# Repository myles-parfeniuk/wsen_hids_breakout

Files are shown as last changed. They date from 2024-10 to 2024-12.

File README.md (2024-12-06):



<summary>Table of Contents</summary>
<ol>
<li><a href="#about">About</a></li>
<li><a href="#pcbway-sponsorship">PCBWay Sponsorship</a></li>
<li><a href="#gerber-files">Gerber Files</a></li>
<li><a href="#pcb-renders">PCB Renders</a></li>
<li><a href="#schematic-and-layout">Schematic and Layout</a></li>
<li><a href="#operating-voltages">Operating Voltages</a></li>
<li><a href="#contact">Contact</a></li>
</ol>

# About
Breakout board for [Würth Elektronik 2525020210002](https://www.we-online.com/en/components/products/WSEN-HIDS) I2C humidity w/ integrated temperature sensor IC.   
This repo contains all the schematic and layout files in the form of a KiCad project, they can be found within the `kicad` directory.
<p align="right">(<a href="#readme-top">back to top</a>)</p>

# PCBWay Sponsorship
Special thanks to PCBWay for reaching out to sponsor this project and provide access to their excellent service.  
PCBWay supports the DIY and open source community as well as students with sponsorships and contests frequently.   
Show them some love and consider having your next project fabricated by them: 

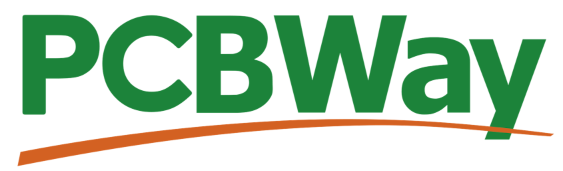
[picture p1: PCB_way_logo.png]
 

Order [here](https://www.pcbway.com/) today.

The boards manufactured by PCBWay had quality that exceeded my expectations.  
The silk screen was less smudged and noticeably more detailed than other fab houses I've used before. All 5 of the boards in my order had no defects, both cosmetic, and functionally.   

The shipping was also insanely quick; I live overseas from China, despite that, with standard shipping the boards were at my place within 2 weeks of uploading the gerbers.    
Their website also had an easy to follow [guide](https://www.pcbway.com/blog/help_center/Generate_Gerber_file_from_Kicad.html) on the settings they require for generated gerbers, this made ordering a breeze. Their [capabilities page](https://www.pcbway.com/capabilities.html) was also easy to follow for setting the constraints within KiCad.  

Overall, I was very satisfied with the result, I'll definitely be using them for any future projects.  

**NOTE:**  

The renders look different from the photos below, as these were for revision 1.0. The renders and KiCad files are for the newest revision, 1.1.

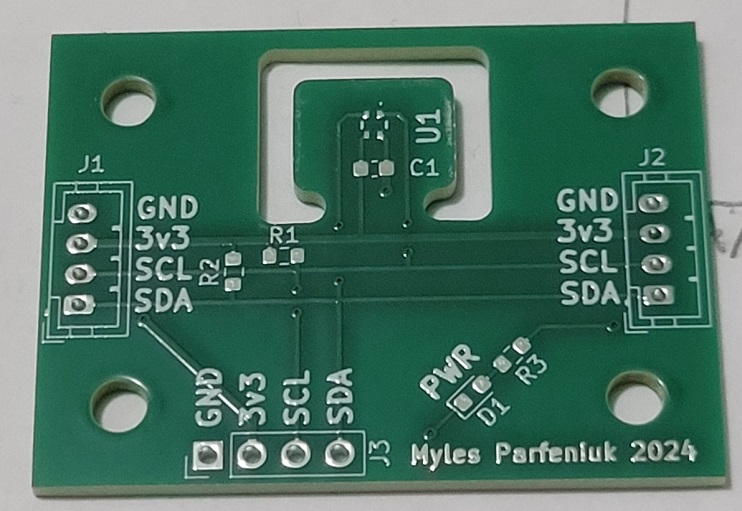
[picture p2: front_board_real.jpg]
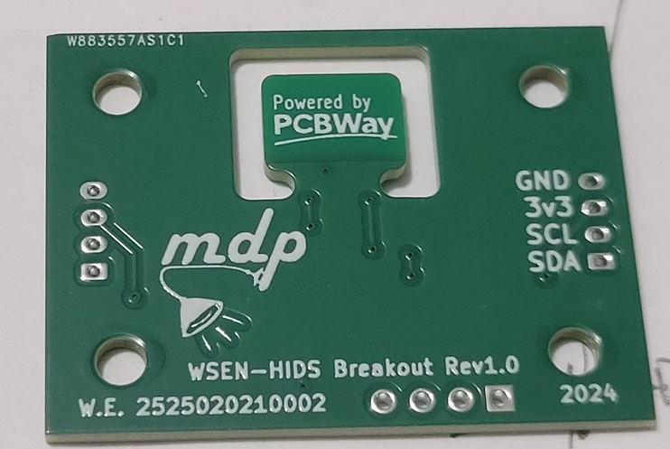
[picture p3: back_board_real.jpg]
  

<p align="right">(<a href="#readme-top">back to top</a>)</p>

# Gerber Files
Generated gerber and drill files can be found within the gerbers.7z archive.   
These files were generated according to PCBWay's desired settings, thus, they can be used to order the boards from them without re-plotting.
<p align="right">(<a href="#readme-top">back to top</a>)</p>

# PCB Renders
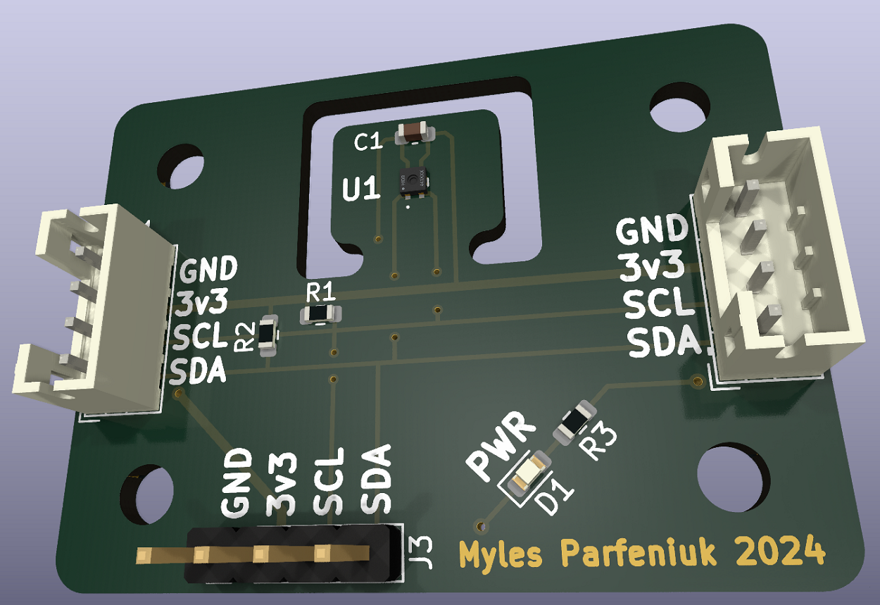
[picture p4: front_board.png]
  

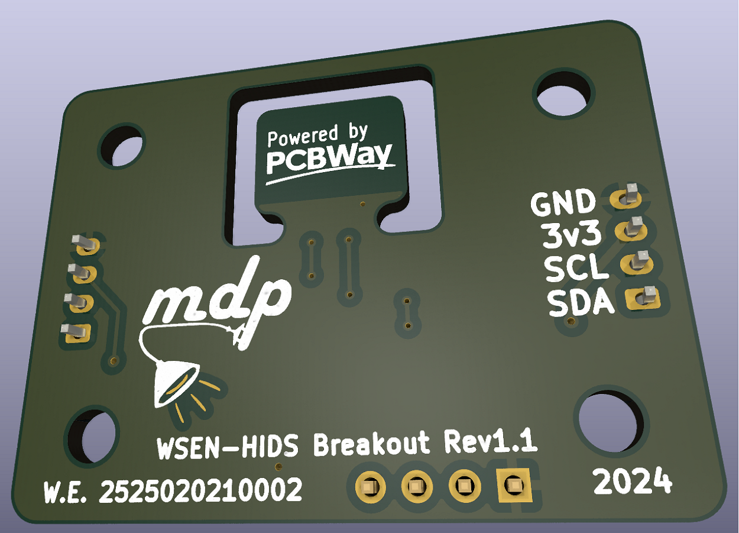
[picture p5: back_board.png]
  
<p align="right">(<a href="#readme-top">back to top</a>)</p>

# Schematic and Layout
 

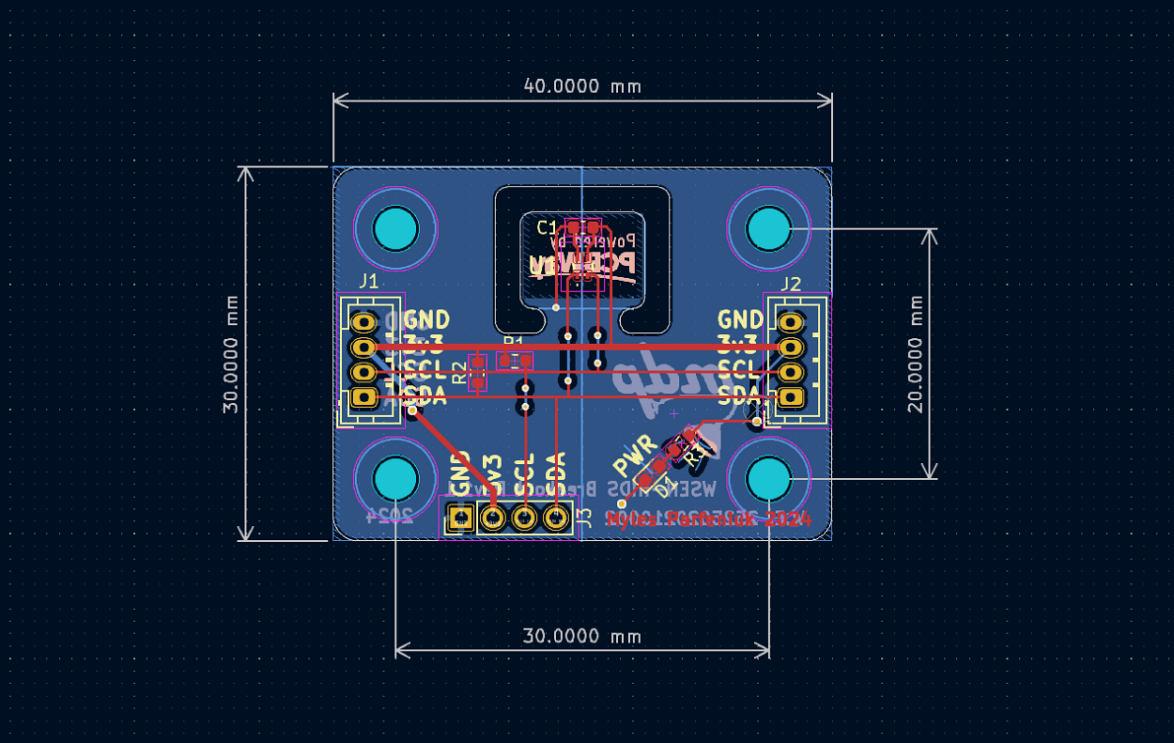
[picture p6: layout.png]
 

<p align="right">(<a href="#readme-top">back to top</a>)</p>

# Operating Voltages
| Pin | Min.| Max. |
|---|---|---|
| 3v3 | 1.08  | 3.6 |
| SCL/SDA | -0.3  | 3.9  |
<p align="right">(<a href="#readme-top">back to top</a>)</p>

# Contact
Myles Parfeniuk — myles.parfenyuk@gmail.com  

Project Link — [myles-parfeniuk/wsen_hids_breakout](myles-parfeniuk/wsen_hids_breakout)
<p align="right">(<a href="#readme-top">back to top</a>)</p>

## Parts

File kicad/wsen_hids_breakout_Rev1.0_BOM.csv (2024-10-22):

# | Reference | Qty | Value | Footprint | Digikey Product #
1 | C1 | 1 | 100n | Capacitor_SMD:C_0603_1608Metric | 311-1341-2-ND
2 | D1 | 1 | LED | LED_SMD:LED_0603_1608Metric | 732-4980-2-ND
3 | J1, J2 | 2 | JST_PH_B4B-PH-K | Connector_JST:JST_PH_B4B-PH-K_1x04_P2.00mm_Vertical | 455-B4B-PH-K-ND
4 | J1, J2 | 2 | JST_PH_B4B-PH-K | Connector_JST:JST_PH_B4B-PH-K_1x04_P2.00mm_Vertical | 455-1164-ND
5 | J3 | 1 | Conn_01x04_Socket | Connector_PinHeader_2.54mm:PinHeader_1x04_P2.54mm_Vertical | n/a
6 | R1, R2 | 2 | 10k | Resistor_SMD:R_0603_1608Metric | RMCF0603JT10K0TR-ND
7 | R3 | 1 | 4.7K | Resistor_SMD:R_0603_1608Metric | RMCF0603FT4K70TR-ND
8 | U1 | 1 | 2525020210002 | BiltongBoardSensorExpansion:2525020210002 | 732-2525020210002TR-ND

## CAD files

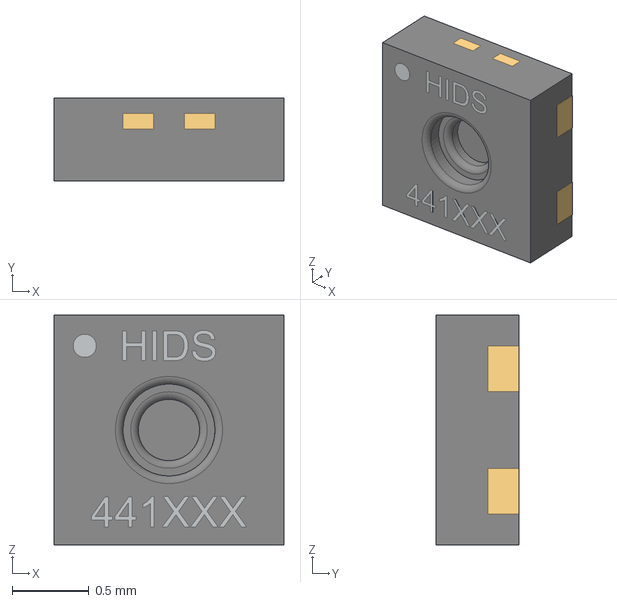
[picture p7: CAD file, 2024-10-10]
kicad/BiltongBoardSensorExpansion3dModels/2525020210002.stp
1.50 x 0.542 x 1.50 mm

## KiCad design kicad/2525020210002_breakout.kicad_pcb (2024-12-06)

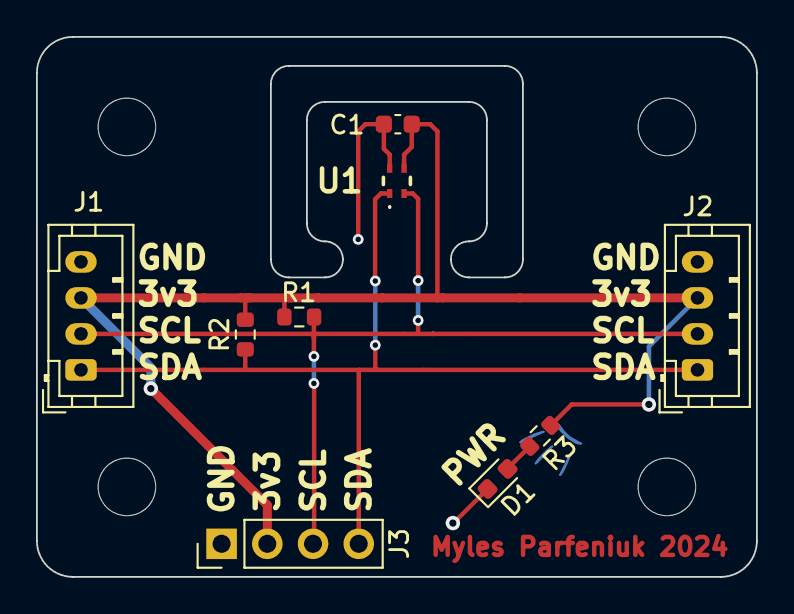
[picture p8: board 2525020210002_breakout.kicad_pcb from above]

Board: 2 copper layers, 40.0 x 30.0 mm, 13 parts (0 on the bottom side), 5 nets.

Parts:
C1: 100n; C_0603_1608Metric
D1: 150060VS7500; LED_0603_1608Metric
H1, H2, H3, H4: MountingHole M3; MountingHole_3.2mm_M3
J1, J2: JST_PH_B4B-PH-K; JST_PH_B4B-PH-K_1x04_P2.00mm_Vertical
J3: Conn_01x04_Socket; PinHeader_1x04_P2.54mm_Vertical
R1, R2: 10k; R_0603_1608Metric
R3: 4.7K; R_0603_1608Metric
U1: 2525020210002

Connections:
+3V3: C1.1, J1.3, J2.3, J3.2, R1.2, R2.2, R3.2, U1.3 (VDD)
/I2C1_SCL: J1.2, J2.2, J3.3, R1.1, U1.2 (SCL)
/I2C1_SDA: J1.1, J2.1, J3.4, R2.1, U1.1 (SDA)
GND: C1.2, D1.1 (K), J1.4, J2.4, J3.1, U1.4 (VSS)
unnamed: D1.2 (A), R3.1

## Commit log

2024-10-10 added kicad project files
    [2525020210002.stp, 2525020210002_breakout.kicad_pcb, 2525020210002_breakout.kicad_sch]
2024-10-10 README.md update, schematic m.hole sz lbl
    [2525020210002_breakout.kicad_pcb, 2525020210002_breakout.kicad_sch]
2024-10-10 fixed pin name in README.md
2024-10-10 fxd exposed gnd, add r.ss lbls, PCBWay sponsorship
    [2525020210002_breakout.kicad_pcb]
2024-10-11 fixed all DRC violations
    [2525020210002_breakout.kicad_pcb]
2024-10-11 modified pwr diode trace
    [2525020210002_breakout.kicad_pcb]
2024-10-11 generated gerber+drill files
    [2525020210002_breakout.kicad_pcb]
2024-10-16 changed solid ground connections to thermal reliefs
    [2525020210002_breakout.kicad_pcb]
2024-10-22 generated BOM, fixed fab layer error
    [2525020210002_breakout.kicad_pcb, 2525020210002_breakout.kicad_sch, wsen_hids_breakout_Rev1.0_BOM.csv]
2024-10-23 missing LED part no.
    [2525020210002_breakout.kicad_pcb, 2525020210002_breakout.kicad_sch]
2024-12-06 Swapped SDA & SCL pins, rounded edgecuts
    [2525020210002_breakout.kicad_pcb, 2525020210002_breakout.kicad_sch]
